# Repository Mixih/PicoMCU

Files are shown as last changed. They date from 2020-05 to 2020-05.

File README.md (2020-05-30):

# PicoMCU

General purpose MCU breakout boards. Pico series boards are extra small or low
power and optimized for low profile embedding, and Micro series board are
general purpose development and prototyping boards with rich peripherals for testing.

## Contents

- PicoMEGA 328PB: Tiny (24x25mm) ATMEGA328PB breakout board

## File Layout

- `Lib`: shared component and footprint libraries
- `[Board Name]/`
  - `[Board Name].pro`: Main KiCAD project file
  - `[Board Name]_panelized.pro`: PCB layout panelized to fill 100x100mm fab
    area 

## Detailed Description and Specifications

Here are the details for each of the hardware projects hosted here.

### PicoMEGA 328PB

This is intended to be a general, low power ATMEGA328PB breakout board, sized as
to be small enough to be embedded in other products (i.e. hardware mods). By
keeping the MCU in sleep mode, power consumption can be greatly reduced,
making the 328PB a viable option for battery powered electronics.

**Feature:**
- Ultra-low quiescent (Iq = 400nA typ) current 3V3 switching regulator (300mA max) 
  w/ regulator bypass jumper for higher power.
- External crystal (designed for 8Mhz max system clock) with compensation caps
- AVCC supply filtering per Atmel AN042 (omit by jumpering over)
- Reset ESD protection and debounce/ext pullup
- ISCP header
- All hardware pins broken out (no more microwire to pad prototyping)
- Optional indication LED connected to pin E1 for status indication needs
  (leave unpopulated if using TWI1 or low power)

**Intentional Omissions:**
- PWR/UART Status LED: Waste of quiescent power. Kludge in if needed.
- Reset button: takes too much space. Use jumper wire instead if manual reset
  is needed

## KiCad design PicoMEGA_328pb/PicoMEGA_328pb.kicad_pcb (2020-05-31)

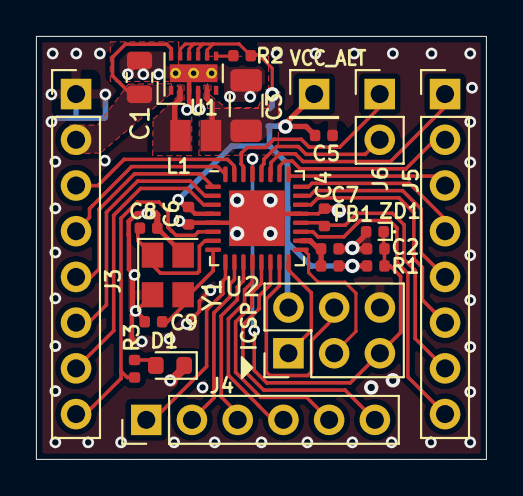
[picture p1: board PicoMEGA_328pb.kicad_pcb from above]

Board: 2 copper layers, 25.0 x 23.5 mm, 26 parts (1 on the bottom side), 36 nets.

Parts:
C1: 10u; C_0805_2012Metric
C2, C4, C6, C7: 0.1u; C_0402_1005Metric
C3: 22u; C_1206_3216Metric
C5: 1u; C_0402_1005Metric
C8, C9: 16p; C_0402_1005Metric
D1: LED; LED_0603_1608Metric
FB1: 220@100Mhz; L_0402_1005Metric
J1: ICSP; PinHeader_2x03_P2.54mm_Vertical
J2: 3V3; PinHeader_1x01_P2.54mm_Vertical
J3: GPIO BLK A; PinHeader_1x08_P2.54mm_Vertical
J4: GPIO BLK B; PinHeader_1x06_P2.54mm_Vertical
J5: GPIO BLK C; PinHeader_1x08_P2.54mm_Vertical
J6: GPIO BLK D; PinHeader_1x02_P2.54mm_Vertical
JP1: VREG_ENA; MicroJumper-2_P0.3mm_Open_Pad0.75x1mm
L1: 4.7u; L_0806_2016metric
R1: 15k; R_0402_1005Metric
R2: 100k; R_0402_1005Metric
R3: 500; R_0402_1005Metric
U1: TPS62745DSSR; WSON-12-1EP_3x2mm_P0.5mm_EP1x2.65_ThermalVias
U2: ATmega328PB-MU; QFN-32-1EP_5x5mm_P0.5mm_EP3.1x3.1mm
Y1: 8Mhz; Crystal_SMD_3225-4Pin_3.2x2.5mm
ZD1: D6V3H1U2LP; D_0402_1005Metric

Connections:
+3V3: C5.1, C6.1, FB1.1, J1.2, J2.1, JP1.2, R1.1, U2.4
+9V: C1.1, J3.2, U1.1, U1.12
/3V3_REG: C3.1, JP1.1, L1.2, R2.1, U1.5, U1.8, U1.9, U1.10, U1.11
/AREF: C4.1, J5.7, U2.20
/MISO: J1.1, U2.16
/MOSI: J1.4, U2.15
/PB0: J4.4, U2.12
/PB1: J4.5, U2.13
/PB2: J4.6, U2.14
/PC0: J5.5, U2.23
/PC1: J5.4, U2.24
/PC2: J5.3, U2.25
/PC3: J5.2, U2.26
/PC4: J5.1, U2.27
/PC5: J6.2, U2.28
/PD0: J6.1, U2.30
/PD1: J3.3, U2.31
/PD2: J3.4, U2.32
/PD3: J3.5, U2.1
/PD4: J3.6, U2.2
/PD5: J4.1, U2.9
/PD6: J4.2, U2.10
/PD7: J4.3, U2.11
/PE0: J3.7, U2.3
/PE1: J3.8, R3.2, U2.6
/PE2: J5.8, U2.19
/PE3: J5.6, U2.22
/PG: R2.2, U1.7
/RST: C2.1, J1.5, R1.2, U2.29, ZD1.1
/SCK: J1.3, U2.17
GND: C1.2, C2.2, C3.2, C4.2, C5.2, C6.2, C7.2, C8.1, C9.2, D1.1, J1.6, J3.1, U1.3, U1.4, U1.13, U2.5, U2.21, U2.33, Y1.2, Y1.4, ZD1.2
unnamed: C7.1, FB1.2, U2.18
unnamed: C8.2, U2.7, Y1.1
unnamed: C9.1, U2.8, Y1.3
unnamed: D1.2, R3.1
unnamed: L1.1, U1.2

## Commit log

2020-05-30 PicoMEGA 328PB: Add h/w design files
    Added initial (r0.1c) PicoMEGA ATmega328PB breakout forlow profile
    prototyping applications.
    [PicoMEGA_328pb.kicad_pcb, PicoMEGA_328pb.sch, PicoMEGA_328pb_panelized.kicad_pcb]
2020-05-30 PicoMEGA 328PB: rev0.1d
    Fixed V_in regulator to use input voltage for enable to gurantee the
    regulator powers on when an input voltage is applied.
    [PicoMEGA_328pb.kicad_pcb, PicoMEGA_328pb.sch, PicoMEGA_328pb_panelized.kicad_pcb]
2020-05-31 PicoMEGA 328PB: rev0.1e
    Revised clock area to use guard ring to prevent cross-talk interference
    for adjacent GPIO traces. No such protection of the GPIOs themselves
    though.
    [PicoMEGA_328pb.kicad_pcb, PicoMEGA_328pb.sch, PicoMEGA_328pb_panelized.kicad_pcb]
